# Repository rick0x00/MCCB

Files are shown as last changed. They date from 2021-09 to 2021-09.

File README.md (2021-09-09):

# MCCB
MODULO DE CONTROLE DE CARRINHO DE BRINQUEDO

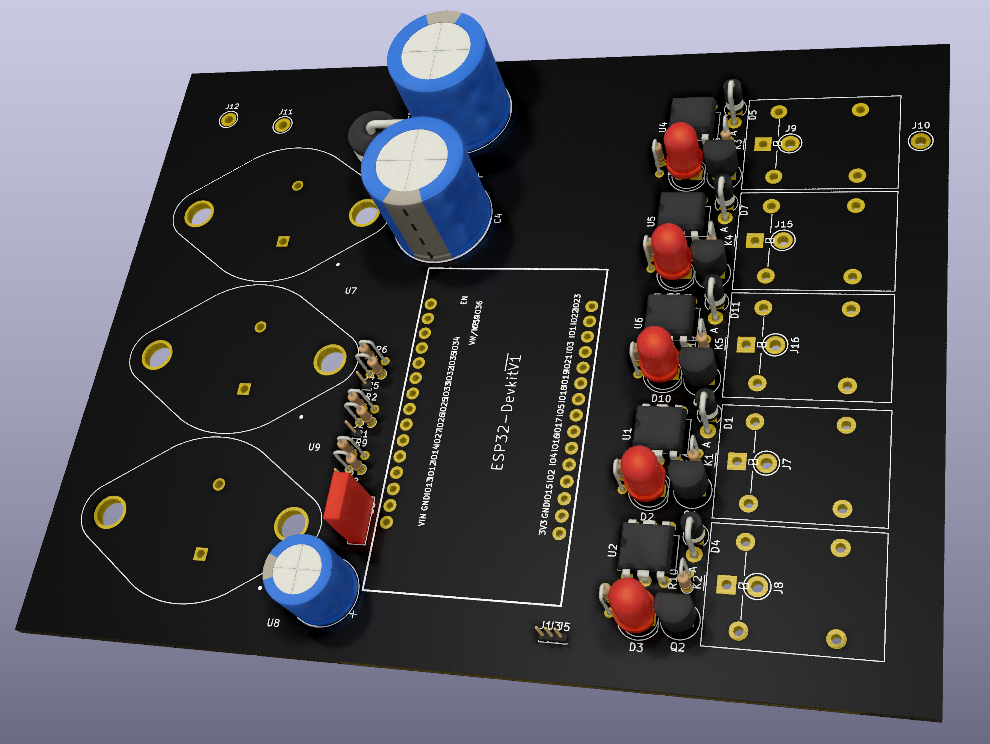
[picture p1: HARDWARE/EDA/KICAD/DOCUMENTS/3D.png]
mccb_3D


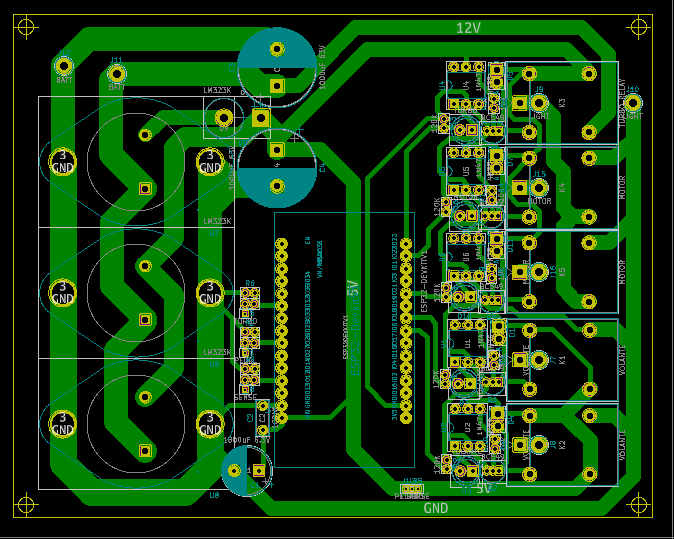
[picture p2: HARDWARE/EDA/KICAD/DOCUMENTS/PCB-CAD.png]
mccb_PCB-CAD


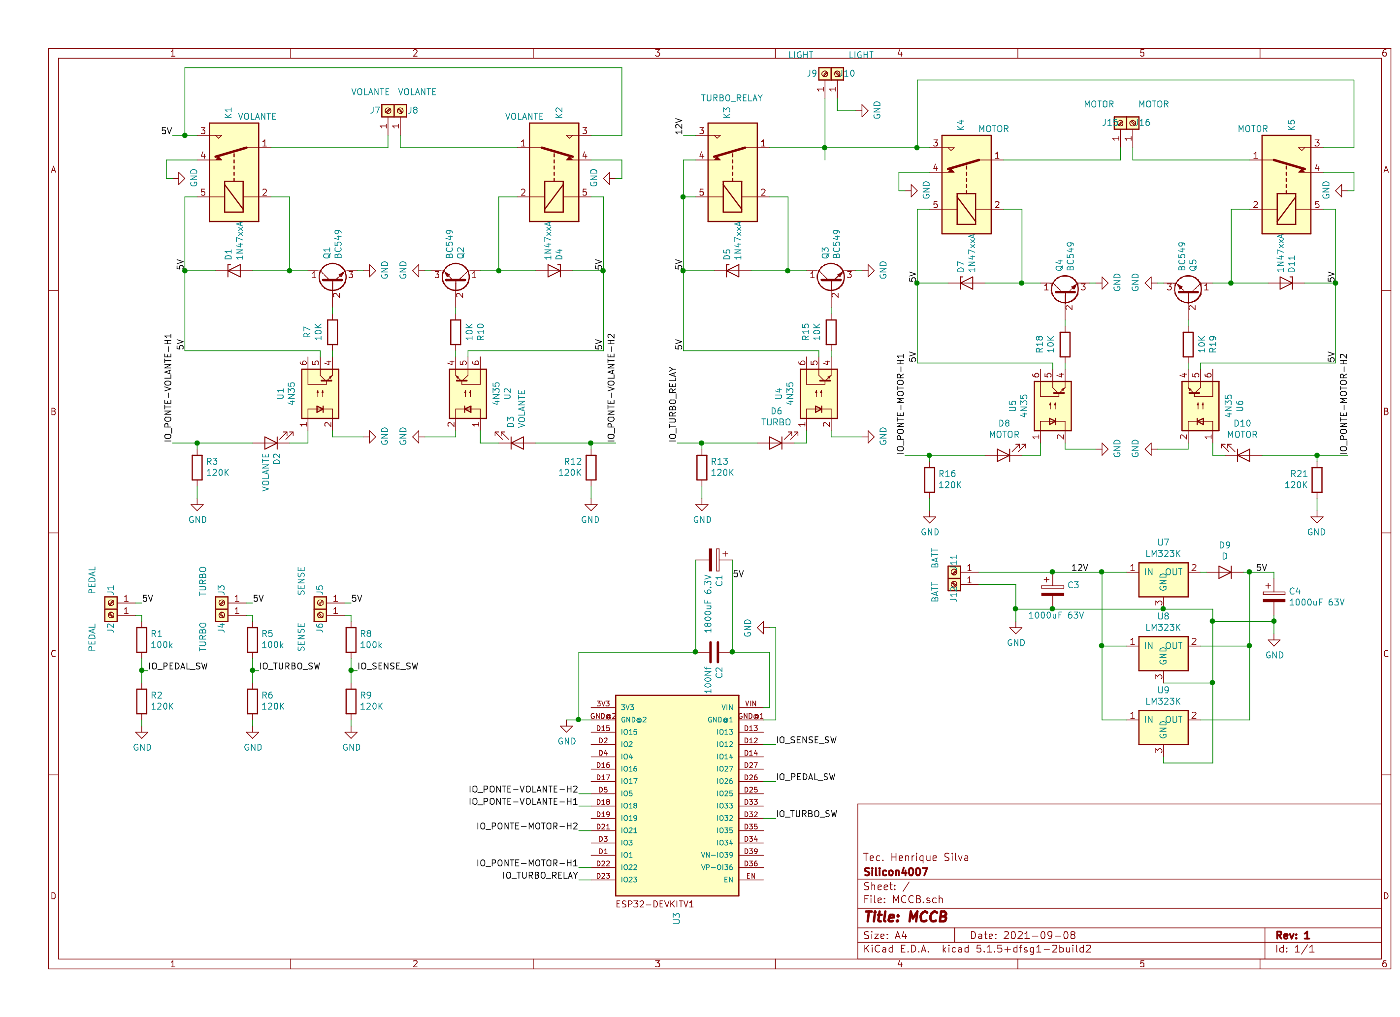
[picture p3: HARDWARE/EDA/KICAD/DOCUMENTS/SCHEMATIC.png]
mccb_SCHEMATIC


## Warning
I, the project maintainer ,am a beginner in this Open Source world, Git, GitHub... So I apologize in advance for any problems.

## License
At the present time this project is completely under [Apache 2.0 license](http://www.apache.org/licenses/LICENSE-2.0). All Softwares, All Electronic Designs(Schematics), All Documentation and All 3D Design.

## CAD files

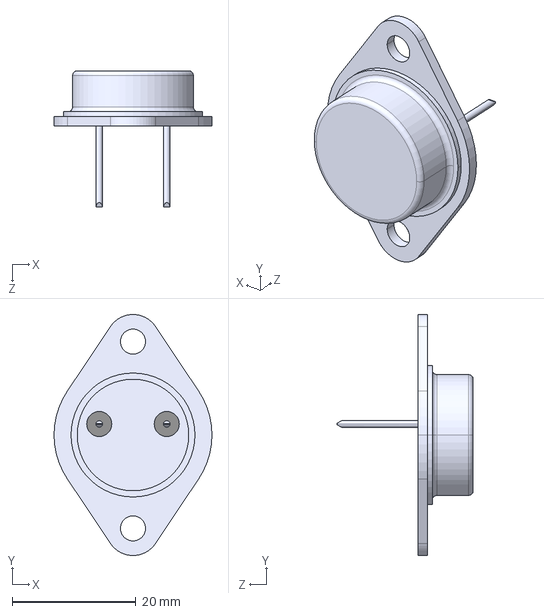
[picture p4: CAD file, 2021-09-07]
HARDWARE/EDA/KICAD/MCCB/COMPLEMENT/TO-3/TO-3.step
25.5 x 38.9 x 22.0 mm

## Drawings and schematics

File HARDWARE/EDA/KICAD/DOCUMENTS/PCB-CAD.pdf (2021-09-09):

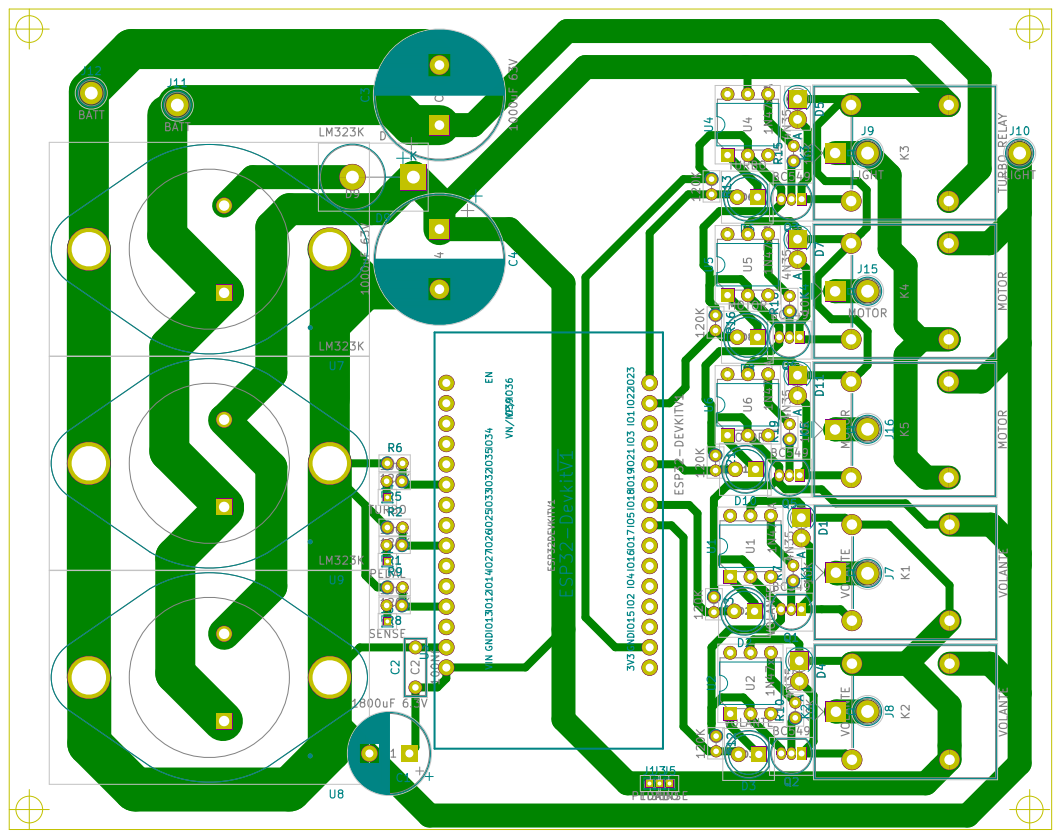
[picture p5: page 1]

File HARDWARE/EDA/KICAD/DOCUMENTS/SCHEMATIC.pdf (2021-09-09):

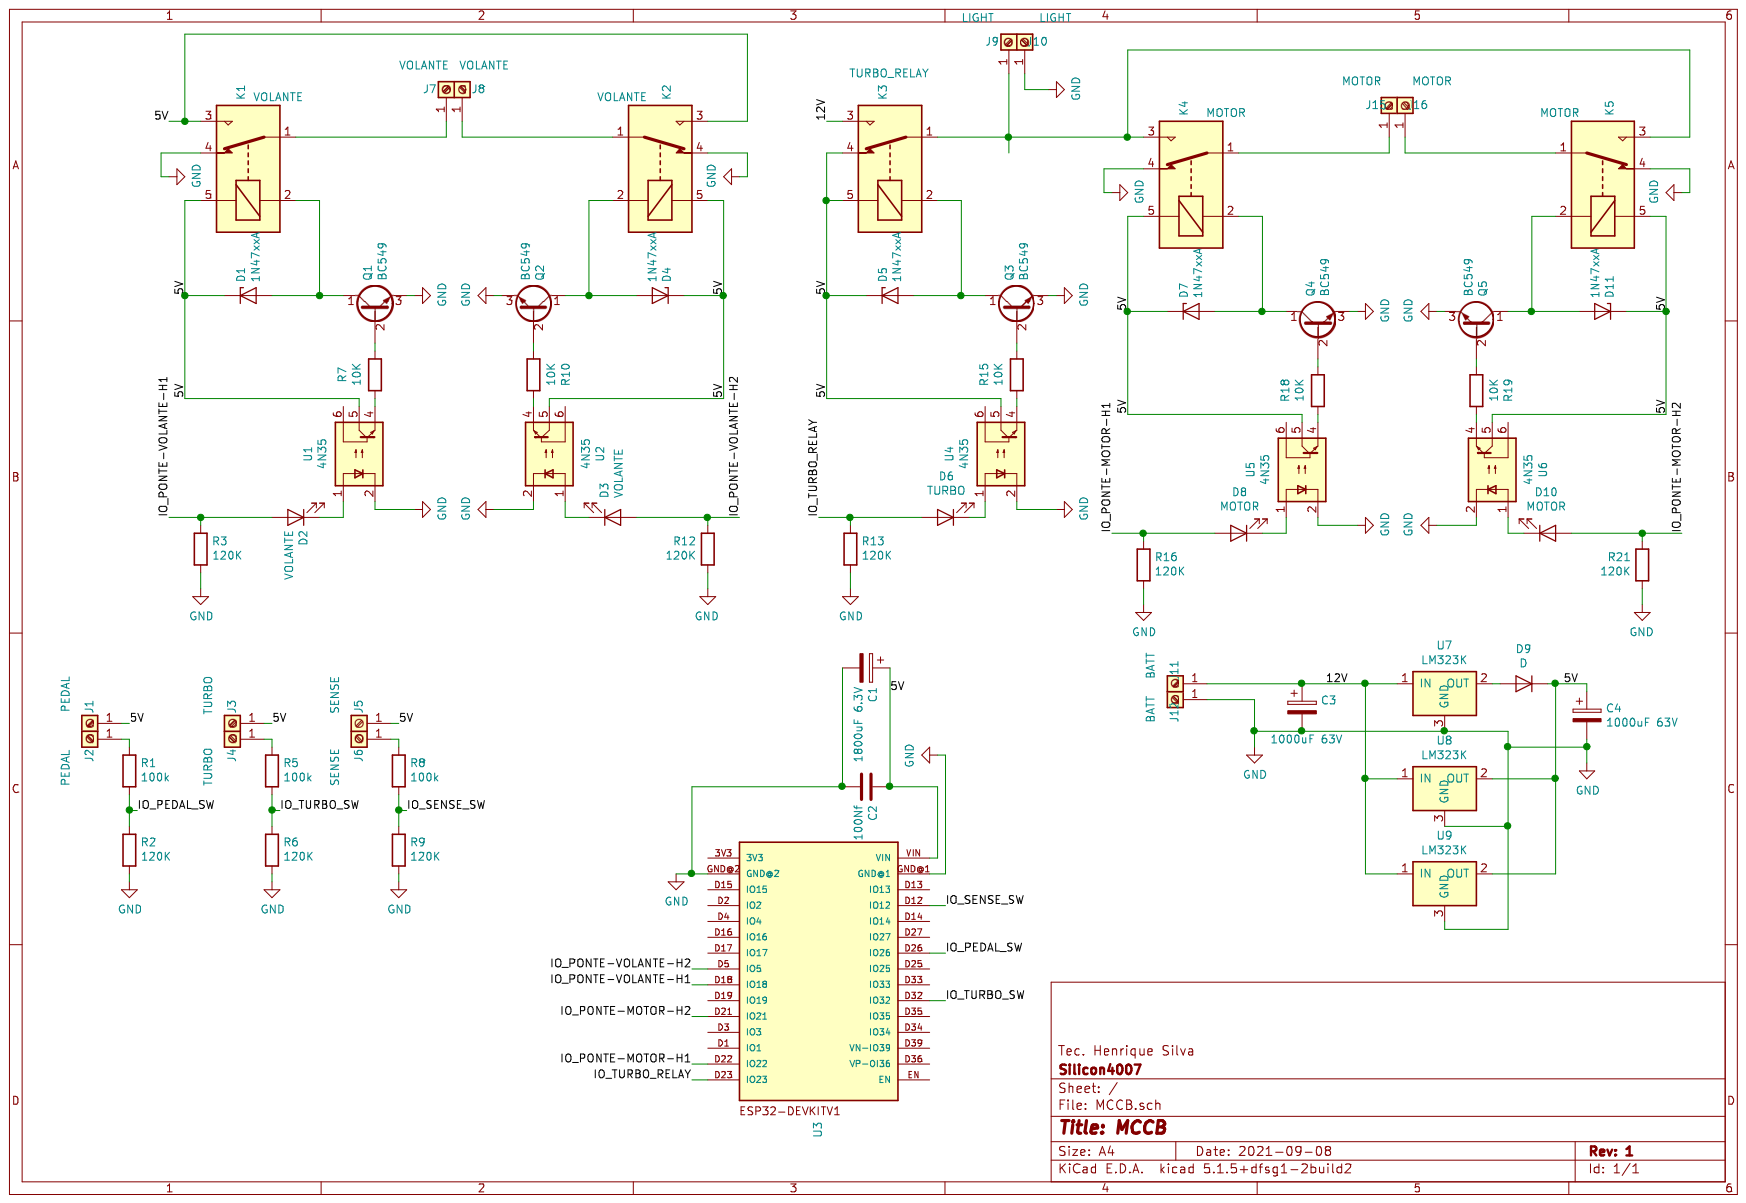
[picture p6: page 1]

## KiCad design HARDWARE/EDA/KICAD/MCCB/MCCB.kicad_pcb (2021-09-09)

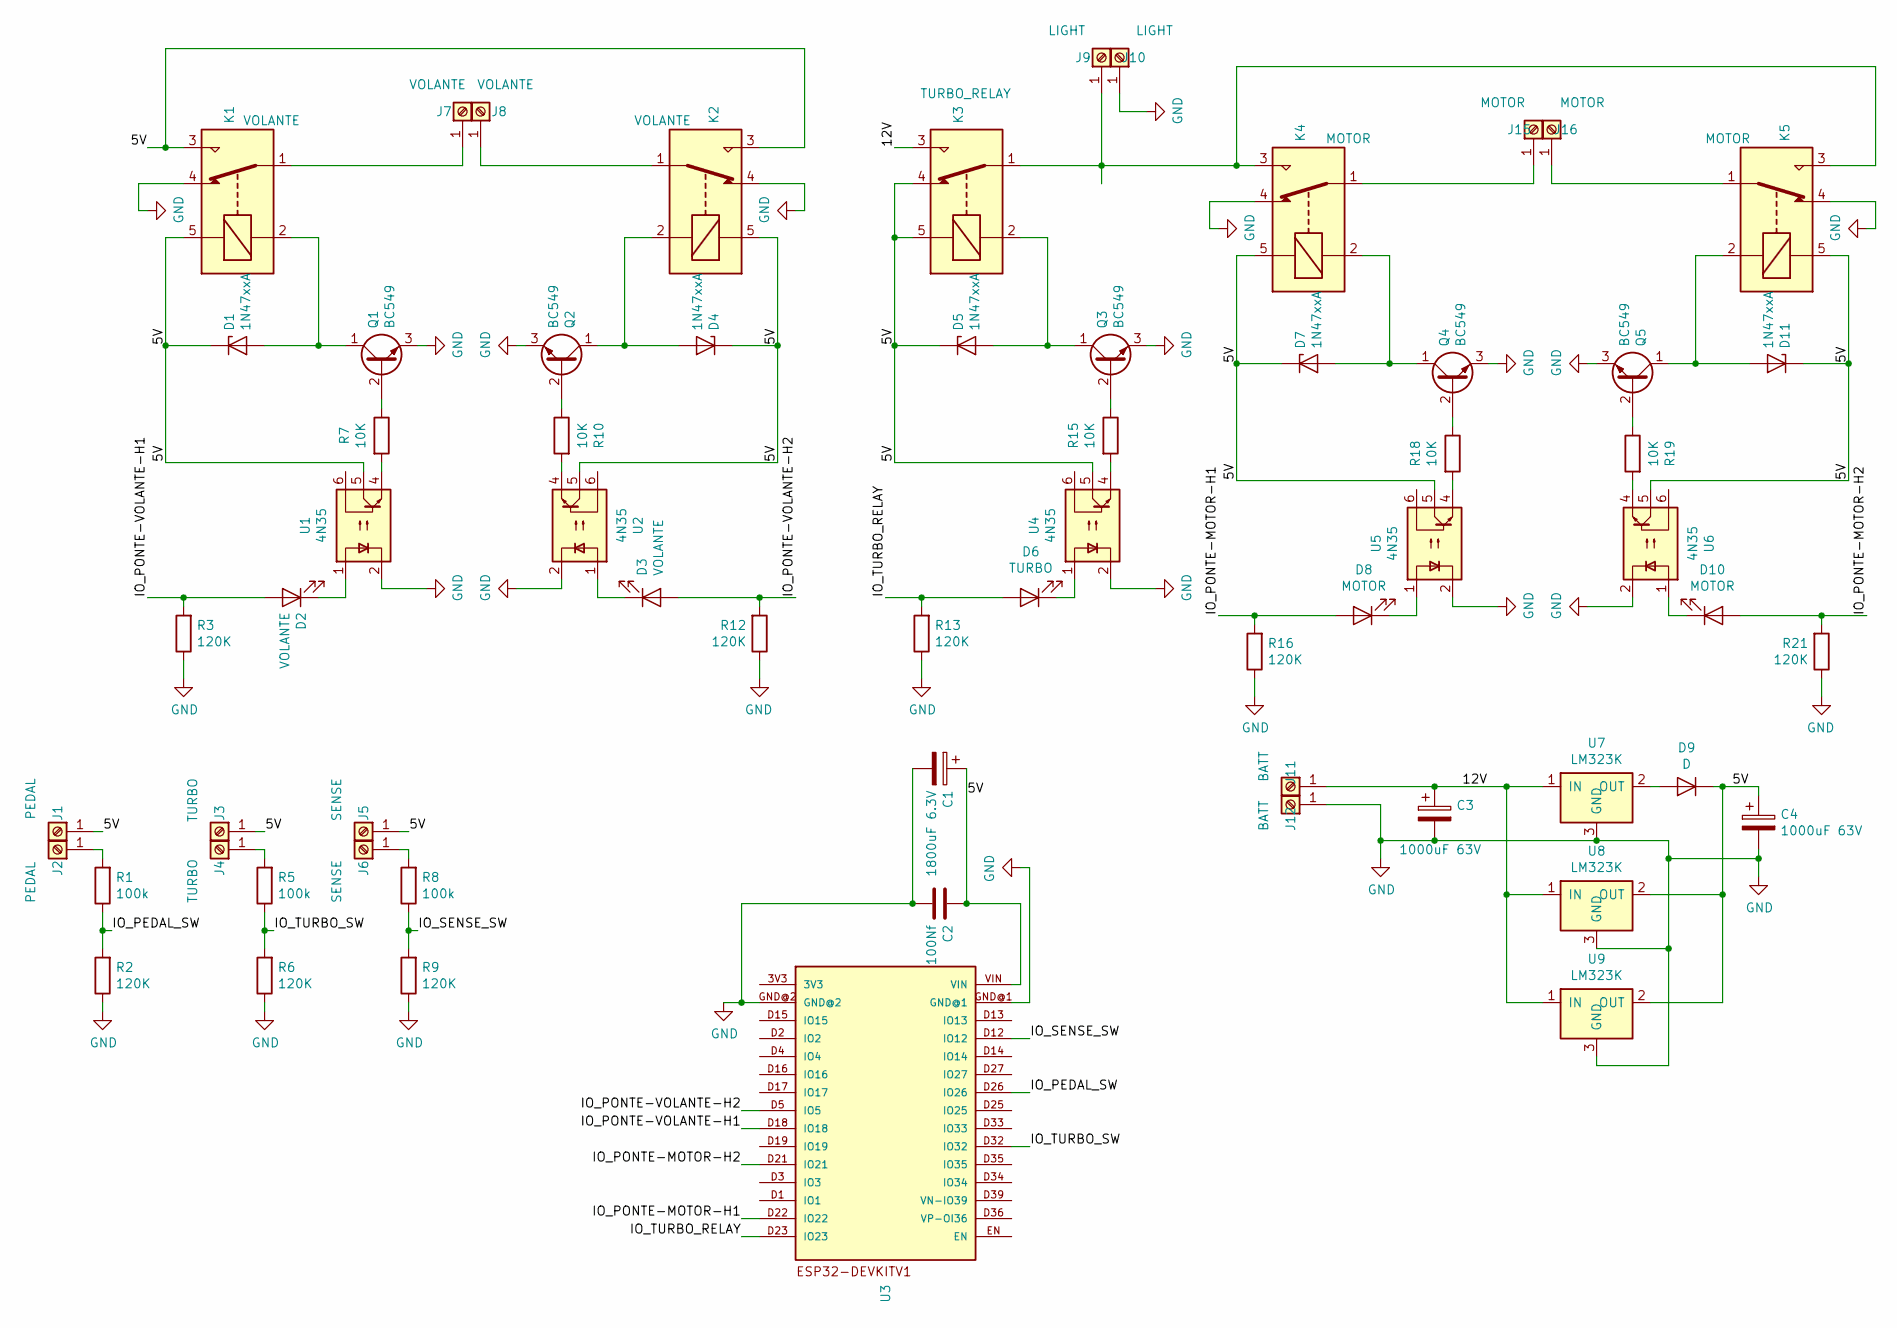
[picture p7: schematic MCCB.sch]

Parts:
C1: 1800uF 6.3V; CP_Radial_D10.0mm_P5.00mm
C2: 100Nf; C_Rect_L7.0mm_W2.5mm_P5.00mm
C3, C4: 1000uF 63V; CP_Radial_D16.0mm_P7.50mm
D1, D4, D5, D7, D11: 1N47xxA; D_DO-41_SOD81_P2.54mm_Vertical_AnodeUp
D2, D3: VOLANTE; LED_D5.0mm
D6: TURBO; LED_D5.0mm
D8, D10: MOTOR; LED_D5.0mm
D9: D; D_5KPW_P7.62mm_Vertical_KathodeUp
J1, J2: PEDAL; PinHeader_1x01_P1.00mm_Vertical
J3, J4: TURBO; PinHeader_1x01_P1.00mm_Vertical
J5, J6: SENSE; PinHeader_1x01_P1.00mm_Vertical
J7, J8: VOLANTE; TestPoint_Keystone_5005-5009_Compact
J9, J10: LIGHT; TestPoint_Keystone_5005-5009_Compact
J11, J12: BATT; TestPoint_Keystone_5005-5009_Compact
J15, J16: MOTOR; TestPoint_Keystone_5005-5009_Compact
K1, K2: VOLANTE; Relay_SPDT_Omron-G5LE-1
K3: TURBO_RELAY; Relay_SPDT_Omron-G5LE-1
K4, K5: MOTOR; Relay_SPDT_Omron-G5LE-1
Q1, Q2, Q3, Q4, Q5: BC549; TO-92_Inline
R1, R5, R8: 100k; R_Axial_DIN0204_L3.6mm_D1.6mm_P1.90mm_Vertical
R2, R3, R6, R9, R12, R13, R16, R21: 120K; R_Axial_DIN0204_L3.6mm_D1.6mm_P1.90mm_Vertical
R7, R10, R15, R18, R19: 10K; R_Axial_DIN0204_L3.6mm_D1.6mm_P1.90mm_Vertical
U1, U2, U4, U5, U6: 4N35; DIP-6_W7.62mm
U3: ESP32DEVKITV1; ESP32-DEVKITV1
U7, U8, U9: LM323K; TO-3

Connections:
/5V: C1.1, C2.1, C4.1, D1.1 (K), D4.1 (K), D5.1 (K), D7.1 (K), D9.1 (K), D11.1 (K), J1.1, J3.1, J5.1, K1.3, K1.5, K2.3, K2.5, K3.4, K3.5, K4.5, K5.5, U1.5, U2.5, U3.VIN, U4.5, U5.5, U6.5, U8.2 (OUT), U9.2 (OUT)
/12V: C3.1, J11.1, K3.3, U7.1 (IN), U8.1 (IN), U9.1 (IN)
/IO_PEDAL_SW: R1.1, R2.2, U3.D26 (IO26)
/IO_PONTE-MOTOR-H1: D8.2 (A), R16.2, U3.D22 (IO22)
/IO_PONTE-MOTOR-H2: D10.2 (A), R21.2, U3.D21 (IO21)
/IO_PONTE-VOLANTE-H1: D2.2 (A), R3.2, U3.D18 (IO18)
/IO_PONTE-VOLANTE-H2: D3.2 (A), R12.2, U3.D5 (IO5)
/IO_SENSE_SW: R8.1, R9.2, U3.D12 (IO12)
/IO_TURBO_RELAY: D6.2 (A), R13.2, U3.D23 (IO23)
/IO_TURBO_SW: R5.1, R6.2, U3.D32 (IO32)
GND: C1.2, C2.2, C3.2, C4.2, J10.1, J12.1, K1.4, K2.4, K4.4, K5.4, Q1.3 (E), Q2.3 (E), Q3.3 (E), Q4.3 (E), Q5.3 (E), R2.1, R3.1, R6.1, R9.1, R12.1, R13.1, R16.1, R21.1, U1.2, U2.2, U3.GND@1, U3.GND@2, U4.2, U5.2, U6.2, U7.3 (GND), U8.3 (GND), U9.3 (GND)
unnamed: D1.2 (A), K1.2, Q1.1 (C)
unnamed: D2.1 (K), U1.1
unnamed: D3.1 (K), U2.1
unnamed: D4.2 (A), K2.2, Q2.1 (C)
unnamed: D5.2 (A), K3.2, Q3.1 (C)
unnamed: D6.1 (K), U4.1
unnamed: D7.2 (A), K4.2, Q4.1 (C)
unnamed: D8.1 (K), U5.1
unnamed: D9.2 (A), U7.2 (OUT)
unnamed: D10.1 (K), U6.1
unnamed: D11.2 (A), K5.2, Q5.1 (C)
unnamed: J2.1, R1.2
unnamed: J4.1, R5.2
unnamed: J6.1, R8.2
unnamed: J7.1, K1.1
unnamed: J8.1, K2.1
unnamed: J9.1, K3.1, K4.3, K5.3
unnamed: J15.1, K4.1
unnamed: J16.1, K5.1
unnamed: Q1.2 (B), R7.1
unnamed: Q2.2 (B), R10.1
unnamed: Q3.2 (B), R15.1
unnamed: Q4.2 (B), R18.1
unnamed: Q5.2 (B), R19.1
unnamed: R7.2, U1.4
unnamed: R10.2, U2.4
unnamed: R15.2, U4.4
unnamed: R18.2, U5.4
unnamed: R19.2, U6.4

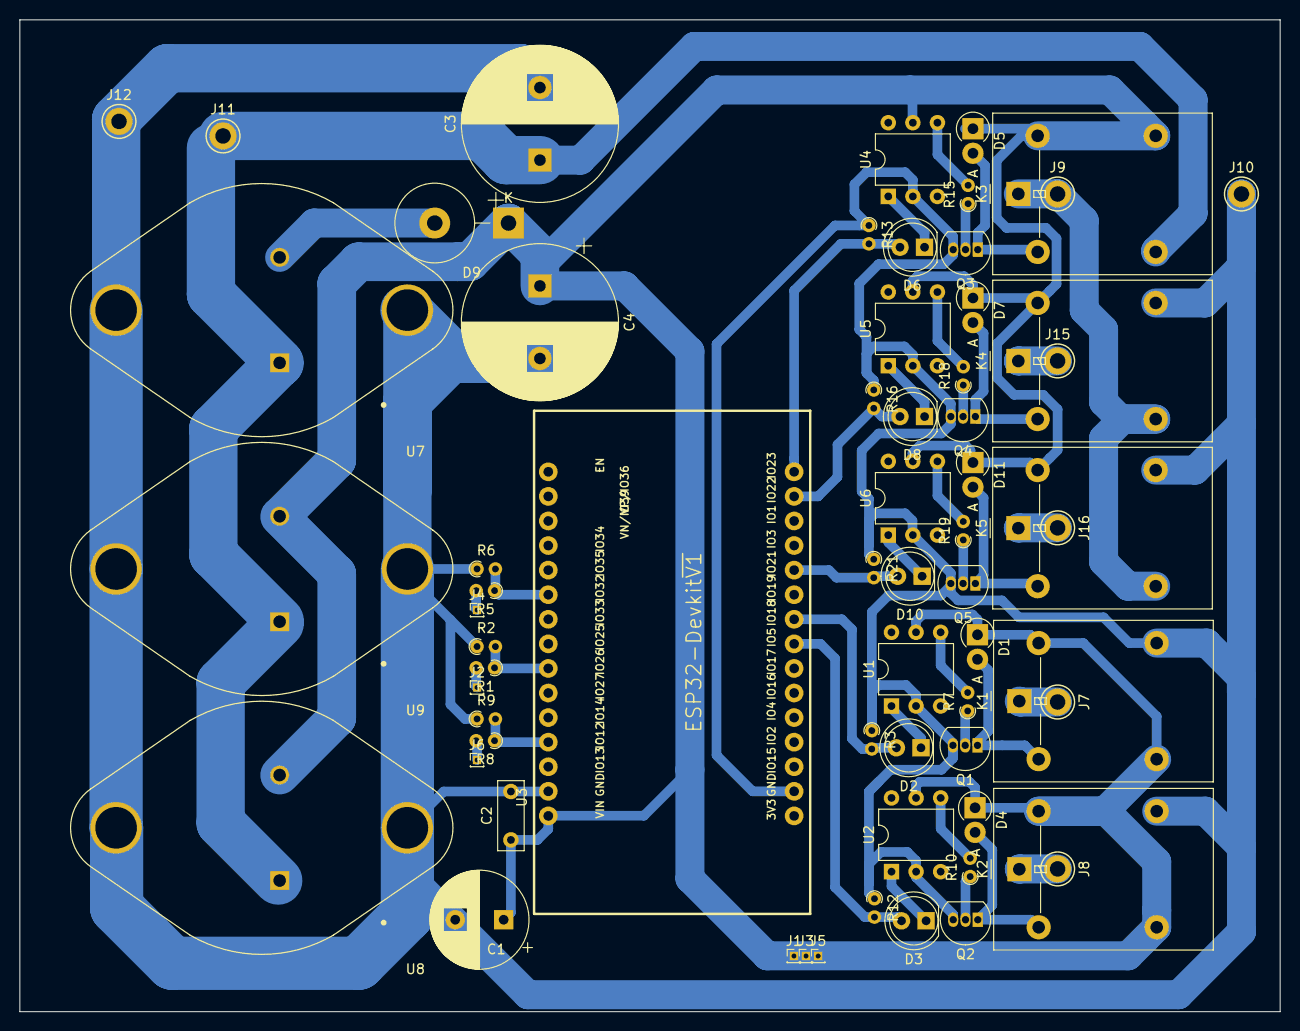
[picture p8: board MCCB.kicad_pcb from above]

Board: 2 copper layers, 130.2 x 102.5 mm, 64 parts (0 on the bottom side), 40 nets.

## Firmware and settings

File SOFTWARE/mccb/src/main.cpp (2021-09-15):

#include <Arduino.h>
// C++ code
//
#define SenseBUT 12
#define PedalBUT 26
#define TurboBUT 32
#define TurboRelay 23
#define MotorRelayH1 22
#define MotorRelayH2 19
#define SteeringWheelRelayH1 5
#define SteeringWheelRelayH2 18
// define led Status ESP 32 Doit DEVKIT V1
#define LedStatus 2

int OLDSenseBUT = 0; //valor de registro de alteração

int SenseBUTtmp = 0; //valor temporário de auxilio
int SenseSW = 0;     //determina o sentido do motor do carrinho;
int OLDSenseSW = 0;  //valor de registro de alteração
int PedalSW = 0;     //determina o movimento do carrinho;
int OLDPedalSW = 0;  //valor de registro de alteração
int TurboSW = 0;     //determina o modo Turbo ligado ou desligado;
int OLDTurboSW = 0;  //valor de registro de alteração

int SteeringWheelSense = 0;    //determina o sentido de volante
int OLDSteeringWheelSense = 0; //valor de registro de alteração

String msgtxt; //criando varável para trafegar mensagens de texto;

String dataSerial; //local de armazenamento dos valos via comunicação serial

int RemoteControlON; // Define se o carro está sendo controlado remotamente

void msg(String txt)
{
    //função criada para ser responsável por qualquer tipo de mensagem;
    msgtxt = txt;
    Serial.println(msgtxt);
}

void StopCar()
{
    msg("Para o carro");
    OLDPedalSW = 0;
    digitalWrite(MotorRelayH1, 0);
    digitalWrite(MotorRelayH2, 0);
}

void SteeringWheelDirection()
{
    //verifica o modo de atuação da ponte H e determina o sentido do volante;
    if (true)
    {
        if (SteeringWheelSense == 1)
        {
            //Volante gira para a direita;
            msg("Volante gira para Direita");
            digitalWrite(SteeringWheelRelayH1, 1);
            digitalWrite(SteeringWheelRelayH2, 0);
        }
        if (SteeringWheelSense == -1)
        {
            //Volante gira para a esquerda;
            msg("Volante gira para Esquerda");
            digitalWrite(SteeringWheelRelayH1, 0);
            digitalWrite(SteeringWheelRelayH2, 1);
        }
        if (SteeringWheelSense != 1 && SteeringWheelSense != -1)
        {
            //volante não gira;
            msg("Volante nao gira");
            digitalWrite(SteeringWheelRelayH1, 0);
            digitalWrite(SteeringWheelRelayH2, 0);
        }
        if (SteeringWheelSense == 0)
        {
            //volante não gira;
            msg("Volante nao gira");
            digitalWrite(SteeringWheelRelayH1, 0);
            digitalWrite(SteeringWheelRelayH2, 0);
        }
    }
}

void Motion()
{
    if (PedalSW == 1)
    {
        if (SenseSW == 1)
        {
            //motor gira em uma direção;
            msg("Motor gira para frente");
            digitalWrite(MotorRelayH1, 1);
            digitalWrite(MotorRelayH2, 0);
        }
        if (SenseSW == -1)
        {
            //motor gira em uma direção oposta;
            msg("Motor gira para tras");
            digitalWrite(MotorRelayH1, 0);
            digitalWrite(MotorRelayH2, 1);
        }
        if (SenseSW != 1 && SenseSW != -1)
        {
            //motor não gira;
            msg("Motor nao gira 1");
            StopCar();
        }
        if (SenseSW == 0)
        {
            //motor não gira;
            msg("Motor nao gira 2");
            StopCar();
        }
    }
}

void SenseSWAUX()
{
    if (RemoteControlON == 0)
    {
        PedalSW = digitalRead(PedalBUT);
    }
    if (true)
    {
        if (PedalSW == 1)
        {
            Motion();
        }
        if (PedalSW == 0)
        {
            StopCar();
        }
    }
}

void SenseState()
{
    if (RemoteControlON == 1)
    {
    }
    if (RemoteControlON == 0)
    {
        SenseBUTtmp = digitalRead(SenseBUT);
    }
    if (SenseBUTtmp != OLDSenseBUT)
    {
        digitalWrite(LedStatus, 1);
        OLDSenseBUT = SenseBUTtmp;
        if (SenseBUTtmp == 1)
        {
            msg("mode go");
            SenseSW = 1;
            SenseSWAUX();
        }
        if (SenseBUTtmp == 0)
        {
            msg("mode back");
            SenseSW = -1;
            SenseSWAUX();
        }
        digitalWrite(LedStatus, 0);
    }
}

void PedalState()
{
    if (RemoteControlON == 1)
    {
        PedalSW = 1;
    }
    if (RemoteControlON == 0)
    {
        PedalSW = digitalRead(PedalBUT);
    }

    //chama a função para determinar o estado do motor;
    if (PedalSW != OLDPedalSW)
    {
        digitalWrite(LedStatus, 1);
        OLDPedalSW = PedalSW;
        if (PedalSW == 1)
        {
            //se o pedal for pressionado, chama a função para liga-lo;
            msg("pedal Pressionado");
            Motion();
        }
        if (PedalSW == 0)
        {
            //se o pedal não for pressionado, chama afunção para desligar o motor;
            msg("pedal livre");
            StopCar();
        }
        digitalWrite(LedStatus, 0);
    }
}

void TurboState()
{
    if (RemoteControlON == 1)
    {
        TurboSW = !TurboSW;
    }
    if (RemoteControlON == 0)
    {
        TurboSW = digitalRead(TurboBUT);
    }

    //define o modo turbo ligado ou desligado;
    if (TurboSW != OLDTurboSW)
    {
        digitalWrite(LedStatus, 1);
        OLDTurboSW = TurboSW;
        if (TurboSW == 1)
        {
            //se o modo turbo for ligado;
            digitalWrite(TurboRelay, 1);
            msg("modo turbo ativado");
            //Liga o rele do modo turbo;
        }
        if (TurboSW == 0)
        {
            //se o modo turbo for desligado;
            digitalWrite(TurboRelay, 0);
            msg("modo turbo desativado");
            //Desliga o rele do modo tubo;
        }
        digitalWrite(LedStatus, 0);
    }
}

void MonitorControl()
{
}

void setup()
{
    Serial.begin(9600); //Define velocidade de Comunicação Serial
    msg("Start Code");
    pinMode(TurboRelay, OUTPUT);
    pinMode(SteeringWheelRelayH1, OUTPUT);
    pinMode(SteeringWheelRelayH2, OUTPUT);
    pinMode(MotorRelayH1, OUTPUT);
    pinMode(MotorRelayH2, OUTPUT);
    pinMode(SenseBUT, INPUT);
    pinMode(PedalBUT, INPUT);
    pinMode(TurboBUT, INPUT);
    pinMode(LedStatus, OUTPUT);
    //-define 0 to all values
    digitalWrite(SteeringWheelRelayH1, 0);
    digitalWrite(SteeringWheelRelayH2, 0);
    digitalWrite(MotorRelayH1, 0);
    digitalWrite(MotorRelayH2, 0);
    digitalWrite(TurboRelay, 0);
    TurboSW = 0;
    SenseSW = 0;
    PedalSW = 0;
    digitalWrite(LedStatus, 1);
    delay(100);
    digitalWrite(LedStatus, 0);
}

void loop()
{
    TurboState();
    SenseState();
    PedalState();
    if (Serial.available())
    { // Verificar se há caracteres disponíveis
        dataSerial = Serial.readString();
        Serial.print(dataSerial);
        Serial.println("");
        if (dataSerial == "start" || dataSerial == "s")
        {
            RemoteControlON = 1;
            msg("Start Remote Control");
            msg("comandos possiveis:");
            msg("go");
            msg("back");
            msg("left");
            msg("right");
            msg("run");
            msg("stop");
            msg("turbo");
            msg("exit");
            msg("------------------");
        }
        while (RemoteControlON == 1)
        {
            if (Serial.available())
            {
                dataSerial = Serial.readString();
                Serial.print(dataSerial);
                Serial.println("");
                if (dataSerial == "exit" || dataSerial == "e")
                {
                    RemoteControlON = 0;
                    msg("Stop Remote Control");
                }
                if (dataSerial == "go" || dataSerial == "g")
                {
                    SenseBUTtmp = 1;
                    SenseState();
                    delay(1100);
                    StopCar();
                }
                if (dataSerial == "back" || dataSerial == "b")
                {
                    SenseBUTtmp = 0;
                    SenseState();
                    delay(1100);
                    StopCar();
                }
                if (dataSerial == "left" || dataSerial == "l")
                {
                    SteeringWheelSense = -1;
                    SteeringWheelDirection();
                    delay(500);
                    SteeringWheelSense = 0;
                    SteeringWheelDirection();
                }
                if (dataSerial == "right" || dataSerial == "r")
                {
                    SteeringWheelSense = 1;
                    SteeringWheelDirection();
                    delay(500);
                    SteeringWheelSense = 0;
                    SteeringWheelDirection();
                }
                if (dataSerial == "run")
                {
                    PedalState();
                    delay(1100);
                    StopCar();
                }
                if (dataSerial == "stop")
                {
                    StopCar();
                }
                if (dataSerial == "turbo" || dataSerial == "t")
                {
                    TurboState();
                }
            }
        }
    }
}
